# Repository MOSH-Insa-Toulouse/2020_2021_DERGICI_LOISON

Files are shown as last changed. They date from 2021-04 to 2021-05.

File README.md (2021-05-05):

# 2020_2021_DERGICI_LOISON

## Plan du Projet Capteur

  - [1. Description](#1-description)
  - [2. Liste des livrables](#2-liste-des-livrables)
  - [3. KiCAD PCB shield - Livrable 1](#3-kicad-pcb-shield---livrable-1)
    - [3.1 Présentation des symboles KiCAD créés](#31-présentation-des-symboles-kicad-créés)
    - [3.2 Rendu 3D du shield designé](#32-rendu-3d-du-shield-designé)
  - [4. Code Arduino - Livrable 2](#4-code-arduino---livrable-2)
  - [5. APK Android interface - Livrable 3](#5-apk-android-interface---livrable-3)
    - [5.1 Notre application: Capteur_Graphite_SDML](#51-notre-application-capteur_graphite_sdml)
    - [5.2 Interface de Capteur_Graphite_SDML](#52-interface-de-capteur_graphite_sdml)
  - [6. Datacheet du capteur - Livrable 4](#6-datacheet-du-capteur---livrable-4)
  - [7. Protocole du banc de test - Livrable 5](#7-protocole-du-banc-de-test---livrable-5)
  - [8. Pistes des améliorations possibles](#8-pistes-des-améliorations-possibles)

## 1. Description 

Ce projet s'inscrit dans l'enseignement de 4éme année génie physique de l'UF "du Banc de Test au Capteur".
Le capteur à réaliser est comparable à une jauge de contrainte à base de graphite.
Le projet comprend:
 - le design et la fabrication d'un PCB shield, 
 - le couplage de la jauge à un circuit analogique, 
 - la communication via un microcontrôleur avec une application Android. 

## 2. Liste des livrables

- [x] KiCAD PCB shield: transimpedance amplifier, BT module, OLED screen
- [x] Code Arduino: mesure jauge contrainte & contrôle communication BT/affichage sur l'OLED
- [x] APK Android interface sur MIT App Inventor: évolution de la valeur de la résistance
- [x] Datasheet du capteur
- [x] Protocole du banc test

Tous les livrales ont été réalisés et sont disponibles sur la plateforme GitHub.

## 3. KiCAD PCB shield - Livrable 1

- PCB simple face designé sur KiCAD :
  - schematics: création d'une biblihothèque dédiée au projet et de nouveaux symboles pour représenter tous les éléments du shield.
  - PCB: routage du circuit transimpédance et des éléments permettant la mesure (module BT, OLED), création des empreintes associées à tous les éléments du shield.
- Accès possible sur GitHub aux fichiers Gerber, à la représentation 3D du shield ainsi qu'aux pdf des pistes

### 3.1 Présentation des symboles KiCAD créés

#### Symbole créé pour le capteur graphite
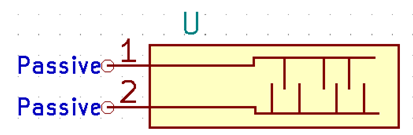
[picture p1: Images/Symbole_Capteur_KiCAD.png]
Symbole du capteur sous KiCAD


#### Symbole créé pour l'écran OLED
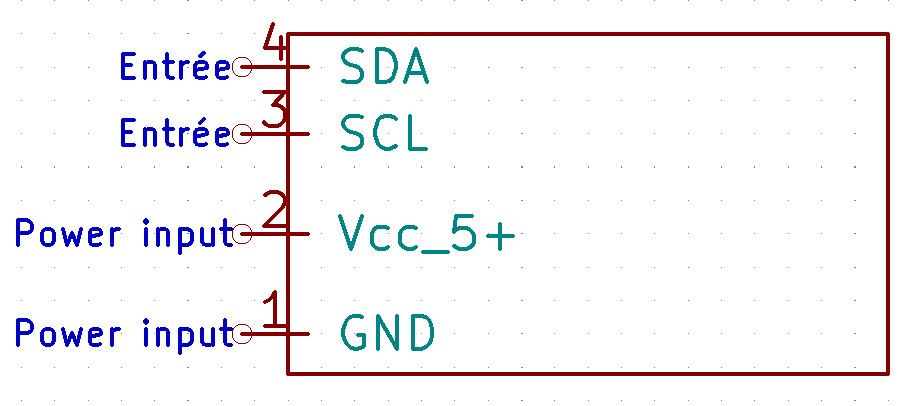
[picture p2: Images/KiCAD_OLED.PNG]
Symbole de l'OLED sous KiCAD


#### Symbole créé pour le module BlueTooth
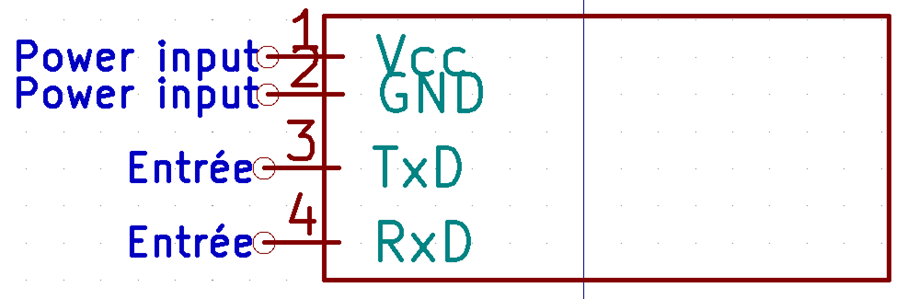
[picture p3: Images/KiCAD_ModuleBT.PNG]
Symbole du module BT sous KiCAD


#### Symbole créé pour l'ampli LTC1050
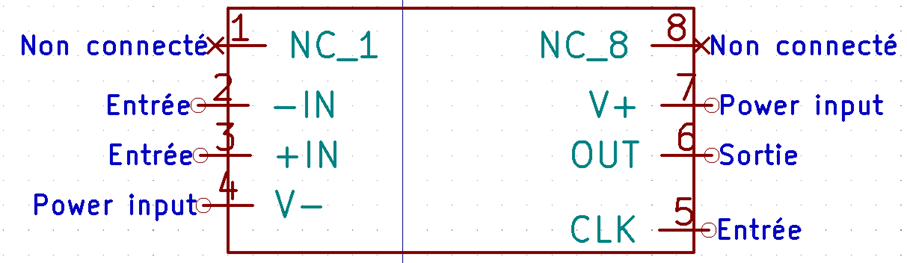
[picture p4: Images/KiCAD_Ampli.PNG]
Symbole de l'ampli LTC1050 sous KiCAD


### 3.2 Rendu 3D du shield designé

#### Représentation 3D du shield
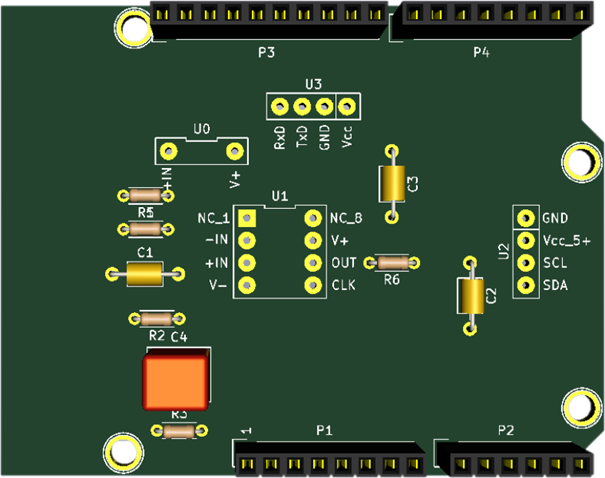
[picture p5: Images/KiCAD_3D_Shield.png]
Représentation 3D du shield


## 4. Code Arduino - Livrable 2

- Le code Arduino permet la communication avec le téléphone portable (réception et envoi de données sous forme de bit), sur la base d'une machine à états il gère ensuite les différents cas de figure possibles.
Trois cas de figures simples ont été imaginés :
   - début de mesure et d'acquisition (correspond au case action=1): lance la mesure et la sauvegarde des données d'ADC et de résistance, affichage de la valeur de résistance sur l'OLED et l'application, graphe de l'appli suit l'évolution des variations de résistance.
   - fin de mesure et arrêt de l'acquisition (correspond au case action=2): arrête la mesure et met fin à la sauvegarde des données qui sont dès lors accessibles sur le téléphone.
   - default case: gère le cas où action a une valeur anormale (différente de 1 ou 2).
  
- Il traduit la valeur en ADC en valeur de résistance, selon l'équation du circuit établie. Pour éviter les erreurs dues à une mauvaise écriture de l'équation (trop ou pas assez de parenthèses) les déterminants, numérateurs et autres ont été préalablement calculés et une variable leur a été affectée.
- Il gère aussi l'affichage des valeurs de résistance sur l'OLED pendant la mesure, et gère l'arrêt de mesure avec l'affichage de l'écran d'accueil sur l'OLED

## 5. APK Android interface - Livrable 3

### 5.1 Notre application: Capteur_Graphite_SDML
- L'application nommée "Capteur_Graphite_SDML" se connecte par bluetooth au capteur 
- L'état de la connexion s'affiche ainsi que le nom de l'appareil connecté
- Mesure la valeur de la résistance selon la déformation appliquée sur le capteur et l'affiche
- Trace le graphique en temps réel des valeurs d'ADC mesurées (choix de l'ADC et non de la résistance pour le graph. car l'ADC varie moins fortement que la résistance)
- Les données sont sauvegardées sous le nom entré par l'utilisateur et accessibles depuis le téléphone 
- L'arrêt de la mesure est annoncé par l'application (déclenche un message vocal)

### 5.2 Interface de Capteur_Graphite_SDML

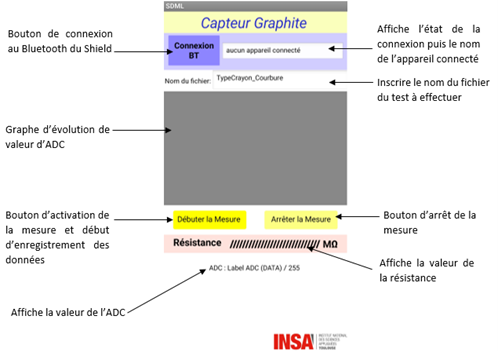
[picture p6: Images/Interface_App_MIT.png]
Interface de l'appli


## 6. Datacheet du capteur - Livrable 4

- Description du capteur et de l'application associée,
- Dimensions du capteur et exemple d'utilisation,
- Présentation du banc de test,
- Caractéristiques techniques et électriques,
- Caractéristiques (Variation de résistance/Déformation),
- Remarques sur les domaines d'utilisation en déformation.

## 7. Protocole du banc de test - Livrable 5

- On utilise un banc de test demi-circulaire des portions de différents rayons. 
- Les rayons sont compris entre 1 cm et 2.5 cm avec un intervalle de 0.25cm. 
- Chaque rayon est associé à une déformation max applicable au capteur graphite.
- La déformation peut être "interne" ou "externe" en fonction du positionnement du capteur. 
- Une petite fente présente a chaque début de courbure permet de coincer l'extrémité du capteur, ce qui permet de bien épouser la surface du banc de test. 
- Pour une meilleure durée de vie du capteur il est préférable de commencer par les rayons les plus grands (torsion et risque de casse du capteur moins)
- À chaque test, les données (la clock, la valeur de la résistance et la valeur de l'ADC) sont enregistrées dans un fichier texte sur le téléphone (nom typique: "myFile_typeCrayon_rayon.txt").
- Une fois tous les tests effectués selon les différents rayons et selon le type de crayon choisi, les données sont traitées.

## 8. Pistes des améliorations possibles

- Le capteur se détériore trop rapidement et on observe une faible reproductibilité des expériences: il est rare de retrouver les même valeurs de résistance pour un même type de crayon. En effet, tout dépend du nombre de couches de graphène déposées sur le capteur. Ce dépôt reste donc très aléatoire.
- Difficultés à mesurer les valeurs de résistance des crayons du type H: leur résistance est trop faible on ne parvient pas à les détecter.
- Difficultés à mesurer les valeurs de résistances des crayons du type 3B et supérieurs: leur résistance est trop élevée il y a overload.
     
     **=> Il s'agit d'un problème de calibration:**
     - Pour adapter le capteur à tous les types de crayons et maximiser les chances d'obtenir plus facilement des données fiables il faut jouer sur la valeur de R2 dans le circuit transimpédance de notre shield
     
     **=> Nous proposons:**
     - Remplacer la résistance R2 par un potentiomètre, ce qui permet d'accéder à une plus grande gamme de résistances et donc de modifier le gain. Une meilleure modulation du gain permettra de s'adapter aux résistances trop élevées ou trop faibles.
     - Installer un encodeur rotatif et mettre au point sur l'Arduino un menu de présélection permettant d'indiquer avant la mesure le type de crayon qui sera utilisé.
     - Adapter le code Arduino pour permettre l'utilisation de l'encodeur rotatif pour naviguer dans le menu de présélection.
     - Adapter le code Aduino pour mettre au point une phase de calibration du potentiomètre R2 suite au choix du type de crayon.
     - Adapter le code Arduino pour communiquer la nouvelle valeur de R2 à l'application Android et au reste du code Arduino (pour les conversions d'ADC en valeur de résistance).
     - Ajouter un autoscale sur le graphique de l'application Android.

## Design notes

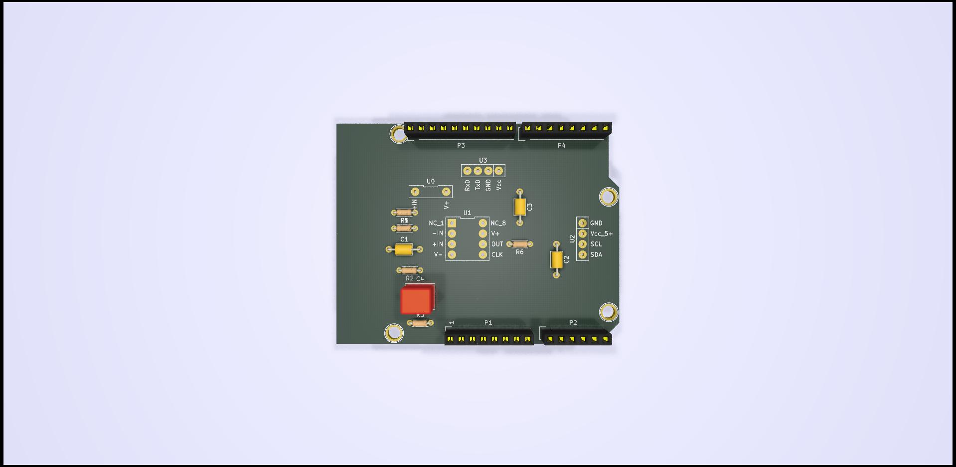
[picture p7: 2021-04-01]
KICAD_capteur_shield/capteur/visu_3D_capteur/visu_3Ddessus_capteur.jpg

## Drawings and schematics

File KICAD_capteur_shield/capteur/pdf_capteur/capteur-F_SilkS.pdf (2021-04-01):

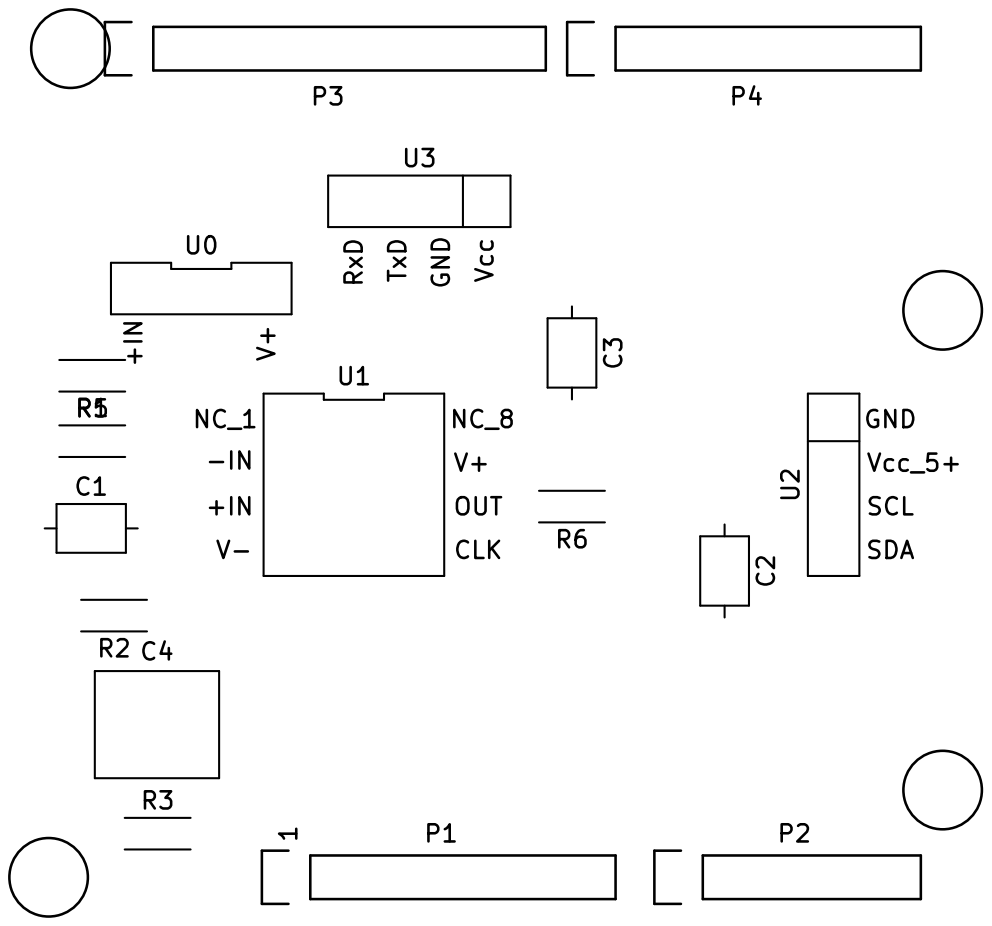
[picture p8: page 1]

1 U3 RxD TxD GND Vcc P1 P2 P3 P4 C1 C2 C3 C4 R1R2 R3 R5 R6 U0 +INV+ U1 NC_1

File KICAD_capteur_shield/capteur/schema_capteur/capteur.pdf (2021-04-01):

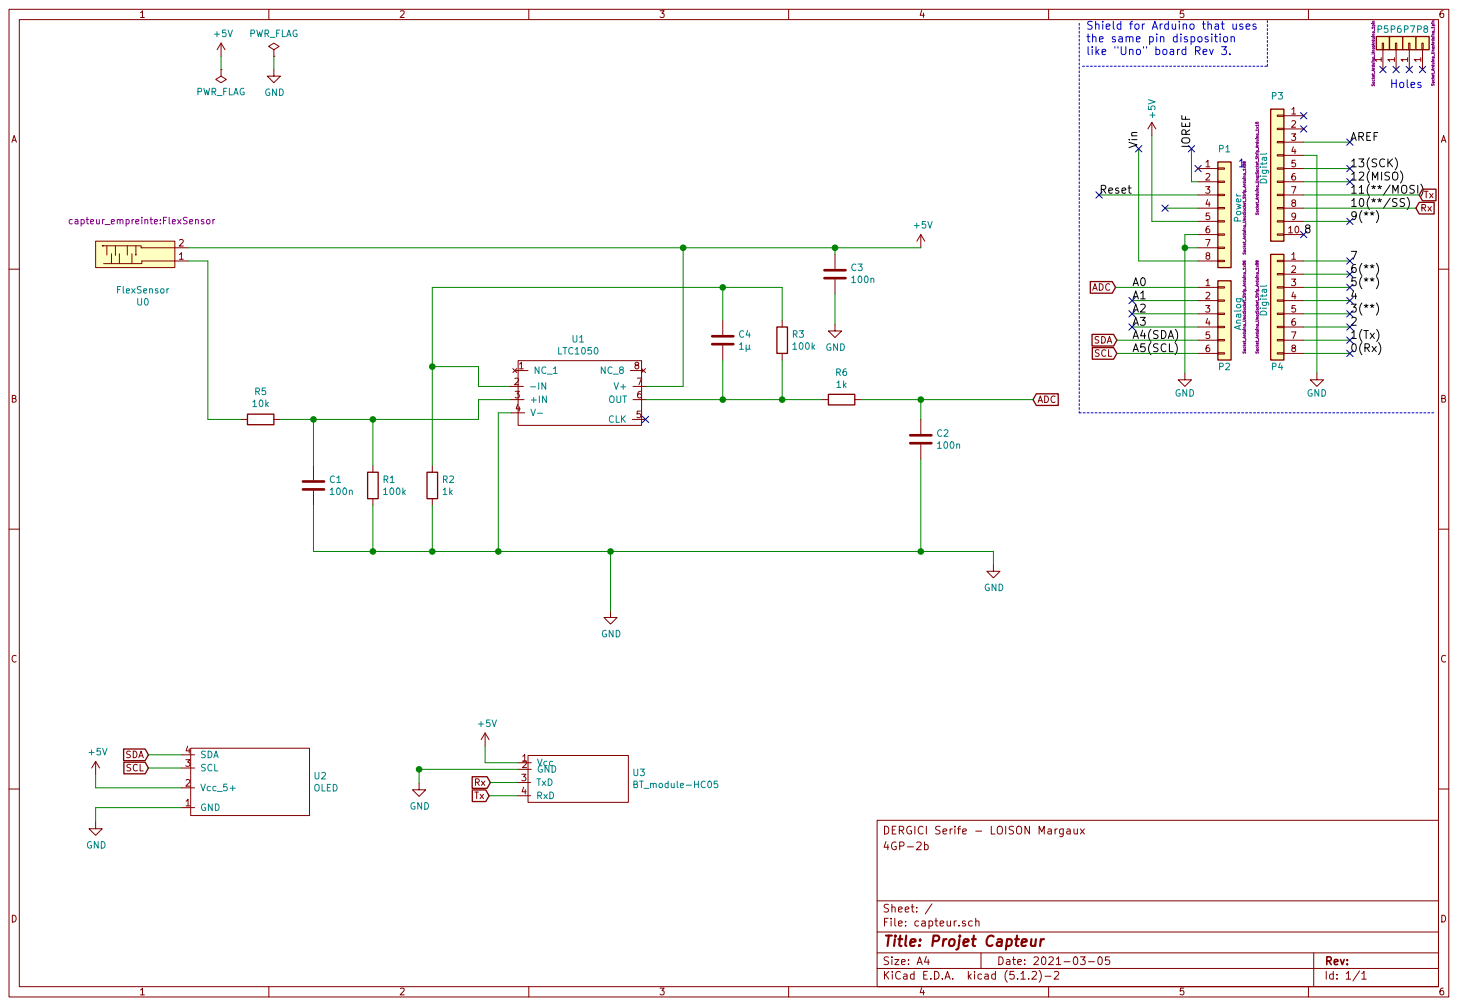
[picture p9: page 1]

the same pin disposition
like "Uno" board Rev 3. 1

Id: 1/1 Title: Projet Capteur

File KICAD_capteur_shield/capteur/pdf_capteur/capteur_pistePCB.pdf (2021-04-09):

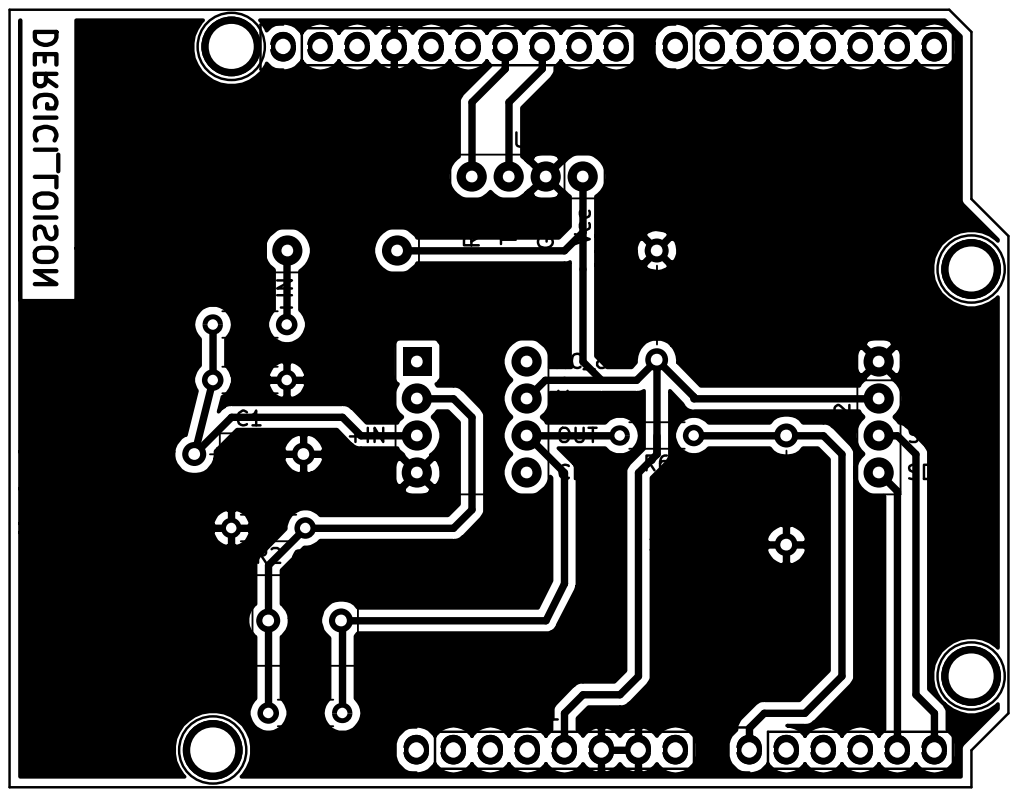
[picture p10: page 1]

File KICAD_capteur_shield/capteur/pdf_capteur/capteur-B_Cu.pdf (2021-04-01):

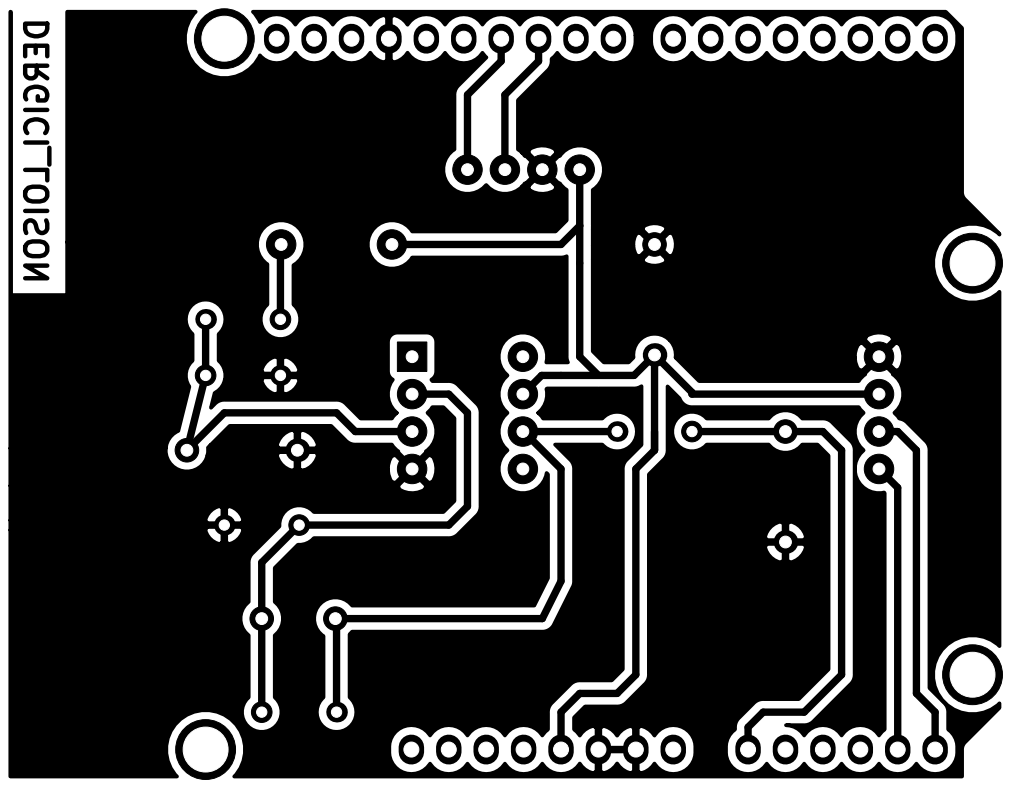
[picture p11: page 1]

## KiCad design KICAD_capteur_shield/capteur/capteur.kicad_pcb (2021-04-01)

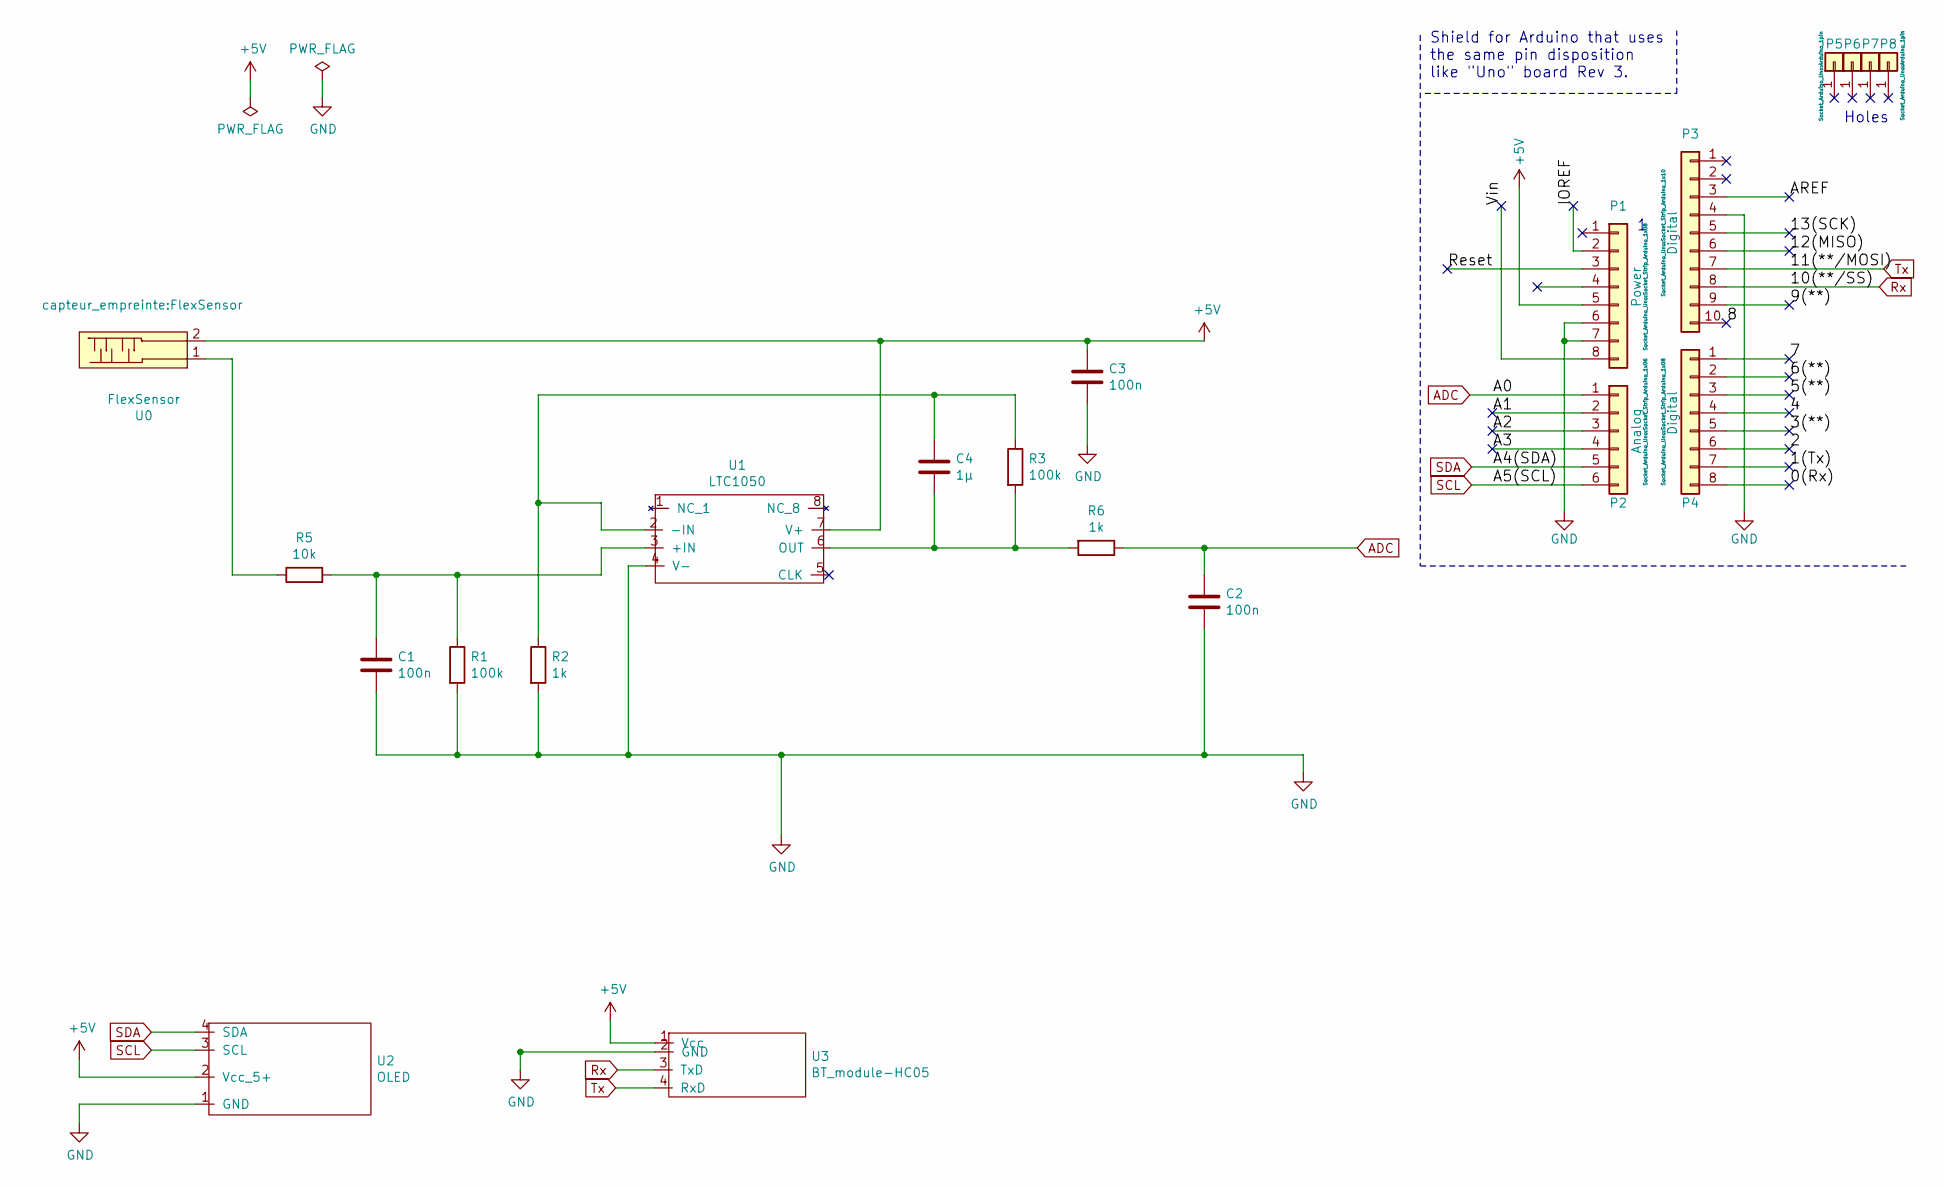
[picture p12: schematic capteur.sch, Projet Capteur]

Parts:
C1, C2, C3: 100n; C_Axial_L3.8mm_D2.6mm_P7.50mm_Horizontal
C4: 1µ; C_Rect_L7.0mm_W6.0mm_P5.00mm
P1: Power; Socket_Strip_Arduino_1x08
P2: Analog; Socket_Strip_Arduino_1x06
P3: Digital; Socket_Strip_Arduino_1x10
P4: Digital; Socket_Strip_Arduino_1x08
P5, P6, P7, P8: CONN_01X01; Arduino_1pin
R1, R3: 100k; R_Axial_DIN0204_L3.6mm_D1.6mm_P5.08mm_Horizontal
R2, R6: 1k; R_Axial_DIN0204_L3.6mm_D1.6mm_P5.08mm_Horizontal
R5: 10k; R_Axial_DIN0204_L3.6mm_D1.6mm_P5.08mm_Horizontal
U0: FlexSensor
U1: LTC1050
U2: OLED
U3: BT_module-HC05

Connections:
+5V: C3.2, P1.5, U0.2, U1.7 (V+), U2.2 (Vcc_5+), U3.1 (Vcc)
/0(Rx): P4.8
/1(Tx): P4.7
/2: P4.6
/3(**): P4.5
/4: P4.4
/5(**): P4.3
/6(**): P4.2
/7: P4.1
/8: P3.10
/9(**): P3.9
/12(MISO): P3.6
/13(SCK): P3.5
/A1: P2.2
/A2: P2.3
/A3: P2.4
/AREF: P3.3
/IOREF: P1.2
/Reset: P1.3
/Vin: P1.8
ADC: C2.1, P2.1, R6.1
GND: C1.2, C2.2, C3.1, P1.6, P1.7, P3.4, R1.2, R2.2, U1.4 (V-), U2.1 (GND), U3.2 (GND)
unnamed: C1.1, R1.1, R5.2, U1.3 (+IN)
unnamed: C4.1, R2.1, R3.1, U1.2 (-IN)
unnamed: C4.2, R3.2, R6.2, U1.6 (OUT)
unnamed: R5.1, U0.1
Rx: P3.8, U3.3 (TxD)
SCL: P2.6, U2.3 (SCL)
SDA: P2.5, U2.4 (SDA)
Tx: P3.7, U3.4 (RxD)

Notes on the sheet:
Holes
Shield for Arduino that uses the same pin disposition like "Uno" board Rev 3.

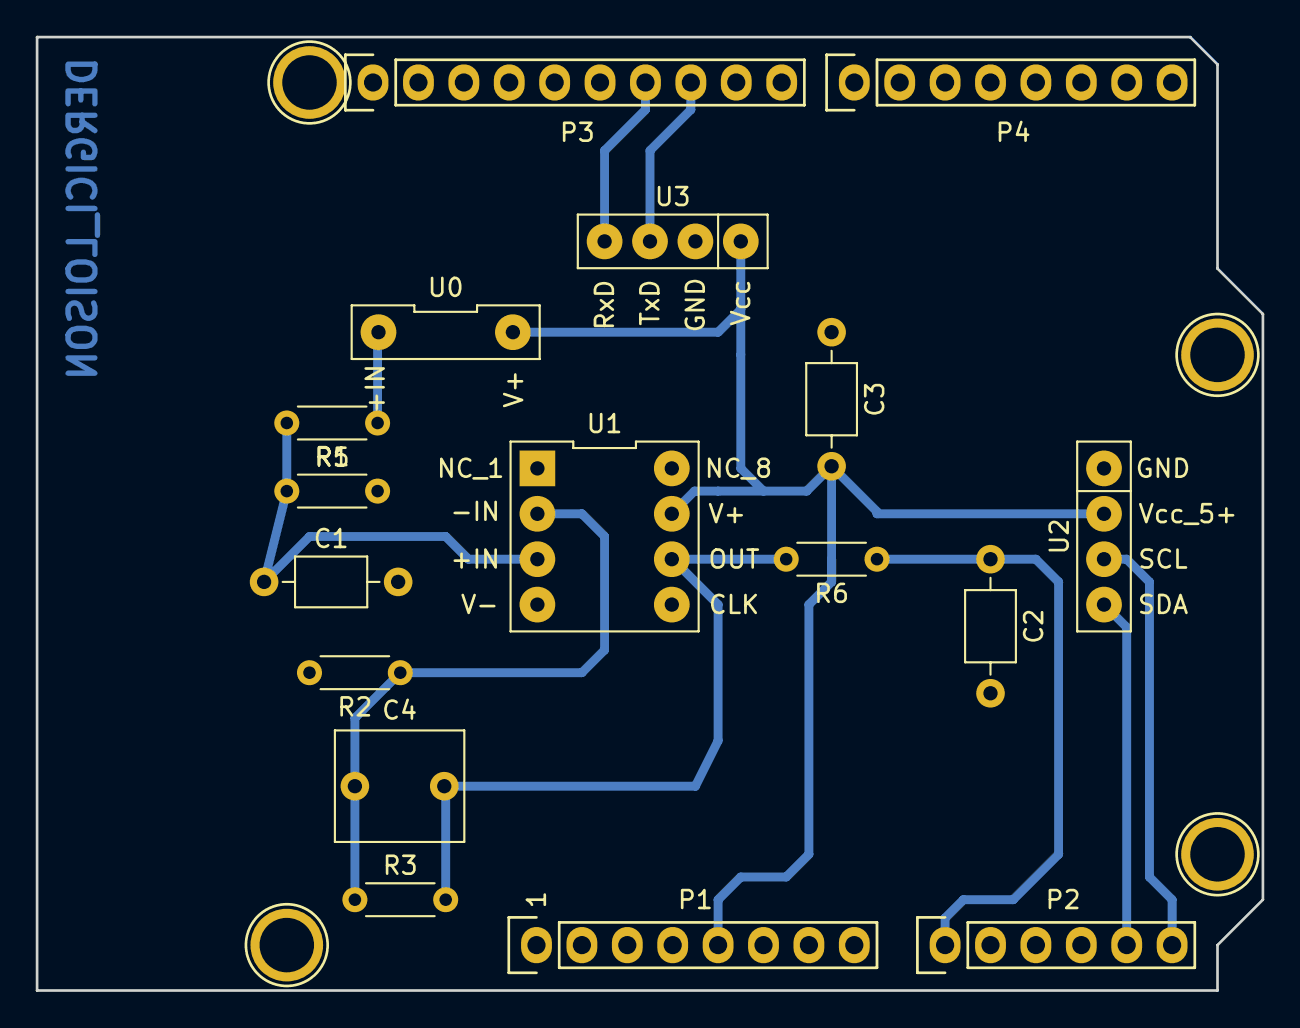
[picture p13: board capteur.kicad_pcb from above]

Board: 2 copper layers, 68.6 x 53.3 mm, 21 parts (0 on the bottom side), 11 nets.

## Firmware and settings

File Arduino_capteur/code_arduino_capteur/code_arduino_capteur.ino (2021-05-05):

//définitions nécessaires à la connexion BT
#include <SoftwareSerial.h>
#define rxPin 10 //cable jaune sur Tx
#define txPin 11 //cable vert sur Rx
#define baudrate 9600
SoftwareSerial mySerial(rxPin, txPin);

//bit qui portera l'information entre l'Arduino et l'application
byte serialRX;

//valeur désignant l'action à réaliser
int action = 0;

//OLED
#include <Adafruit_BusIO_Register.h>
#include <Adafruit_I2CDevice.h>
#include <Adafruit_I2CRegister.h>
#include <Adafruit_SPIDevice.h>

#include <Adafruit_SSD1306.h>
#include <Adafruit_GFX.h>
#include <SPI.h>
#include <Wire.h>

#define oled Adafruit_SSD1306
#define SCREEN_WIDTH 128 // OLED display width, in pixels
#define SCREEN_HEIGHT 32 // OLED display height, in pixels
#define OLED_RESET     4 // Reset pin # (or -1 if sharing Arduino reset pin)

#define SCREEN_ADDRESS 0x3C ///< See datasheet for Address; 0x3C for 128x32
oled display(-1);


//définition des variables nécessaires pour la conversion d'ADC en Résistance
#define A0 0
int valeur = 0;
int R1 = 100000;
int R3 = 100000;
int R2 = 1000;
int R5 = 10000;
int Vcc = 5;

//fonction d'intialilsation de l'OLED au démarrage, l'OLED s'allume et affiche le texte "Projet capteur" dans un rectangle
void demarrage () {
  display.clearDisplay();
  display.setTextSize(1);
  display.setTextColor(WHITE);
  display.clearDisplay();
  display.drawRect (1, 1, 124, 30, WHITE);
  display.setCursor(25, 15);
  display.println("Projet capteur");
  display.display();
  delay(600);
}


//fonction setup, définition des pins et de leur mode, initialisation du serial et de son baudrate
void setup() {
  Serial.begin(9600);
  display.begin(SSD1306_SWITCHCAPVCC, SCREEN_ADDRESS);

  pinMode(rxPin, INPUT);
  pinMode(txPin, OUTPUT);
  mySerial.begin(9600);
  demarrage();
}



// fonction permettant la lecture de la valeur en ADC sur l'arduino
float lectureValeur () {
  valeur = analogRead(A0);
  return valeur;
}

//fonction gérant l'affichage de la valeur de résistance sur l'OLED
void affichage_tension (float valeur) {
  display.clearDisplay();
  display.drawRect (1, 1, 124, 30, WHITE);
  display.setTextSize(1);
  display.setTextColor(WHITE);
  display.setCursor(30, 6);
  display.print("Valeur R =");
  display.setCursor(32, 15);
  float R3R2 = 10100000;//valeur numérique du calcul: R1[1+(R3/R2)]
  float VccVmes = 256; //valeur numérique du calcul: [Vcc/(value*4/1024)*Vcc]
  float R1R5 = 110000; //valeur numérique du calcul: (R1+R5)
  float val_res = ((R3R2 * VccVmes) / (valeur)) - R1R5; //conversion ADC en Résistance
  display.print(val_res /1000000); //pour obtenir une valeur en MOhm
  display.println("  MOhm");
  display.display();
}

//loop du programme: une machine à états permet de gérer les deux cas de figure simples imaginés: le lancement de mesure et l'arrêt de mesure
void loop() {
  while (mySerial.available()) {
    serialRX = mySerial.read();//lecture du bit envoyé par l'application: 2 cas possibles
    switch (serialRX) {
      case 1: //serialRX=1 permet d'engager la mesure
        action = 1;
        break;
      case 2: //serialRX=2 met fin à la mesure
        action = 2;
        break;
      default: break;
    }
  }
  switch (action) {
    case 1://code arduino permettant d'afficher la valeur sur l'OLED et d'envoyer à l'appli
      //valeur envoyée est en byte pour l'avoir en entier
      byte val = map(lectureValeur(), 0, 1024, 0, 255);
      mySerial.write(val); //write directement la valeur en ADC
      Serial.println(val);
      affichage_tension(val); //affiche la résistance du capteur graphite sur l'OLED
      delay(50);
      break;

    case 2://code arduino permettant de marquer l'arrêt de la mesure
      demarrage (); //il n'y a plus de mesure en cours, l'OLED affiche donc l'écran de démarrage
      break;

    default: break;//default case dans le cas où "action" n'a pas la valeur attendue
  }

}
